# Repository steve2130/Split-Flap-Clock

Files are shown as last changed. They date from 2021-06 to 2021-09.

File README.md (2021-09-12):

# Split Flap Clock
I'm addicted to split flap display after accidently watching some Youtube videos. I want to make one for myself, however, choices in the market are either kinda crap or too expensive for a sucker like me.
So I try to make one.

So this flap clock is basically a clone of Solari Cifra 3 (the same company who made airports' flap boards). Instead of making a simple clock like Cifra 3, I decided to fuck myself up and make one that has different functions. Timer, Stopwatch, update time automatically with a NTP server, something like that. 

So basically you will see some fucked up CADs and some stupid code in the future. Hopefully I can actually make a workable clock. 
  
## Extra reading  
gregerw (https://github.com/gregerw/Split-flap-display)  
Tom Lynch (http://unknowndomain.co.uk/)  
JON-A-TRON (https://www.instructables.com/Split-Flap-Display/)  
Danica Evering (http://solaris.concordia.ca/)  
TheBeachLab (https://github.com/TheBeachLab/alphabets/tree/master/V1)  
Scott Bezek (https://github.com/scottbez1/splitflap)  
  
Some parents from the Vestaboard  
https://patents.google.com/patent/US10699605B1  
https://patents.google.com/patent/US20210005116A1

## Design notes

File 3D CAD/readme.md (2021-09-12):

You should see .stl and .f3z here.  
Use Fusion 360 to open .f3z  
.stl is only for viewing on GitHub.

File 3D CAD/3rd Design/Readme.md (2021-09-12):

f for the previous design. It's too big.  
This design is 120mm(L) 65mm(W) 85mm(H) big, so it should be ok now.  
  
No f3z because it is too big (>25MB)

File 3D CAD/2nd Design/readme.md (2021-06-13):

# 2nd Design
So this design is *way* better than the previous version.  
Shout out to gregerw (https://github.com/gregerw/Split-flap-display) for his brillant idea on the structure. ~~I copied it~~  
However, it is going to cost more than the previous design. All the structure of this design is going to be 3D printed.  
  
**This design might be too big tho**

## Component (Provisonal)  
Motor: 2x 28BYJ-48 (5V) *should be ok?*  
Hall effect sensor: 2x KY-003  
Controller: 1x Arduino Nano  
Power source: 2x 18650 in serial

Trying to control 2x 28BYJ-48 motor with 1x ULN2003. However, ULN2003 only have 7 pairs of in and out pins and I need 8. 74HC959 may be needed?  

## CAD source  
28BYJ-48 Motor model: https://grabcad.com/library/28byj-48-5

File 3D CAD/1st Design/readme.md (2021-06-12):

# First design

__This design is abandoned.__ 

This design uses 3mm MDF as the main structure for the hour and minute module.  
I was trying to design a structure so that it can be easily made with a laser cutter.   
However, the design I made was not strong enough for holding the entire structure together. It involved a LOT of friction mounts.  
As the center axis will going to be 3D printed anyway, this design is scrapped and I ~~shamelessly copied~~ made another design.

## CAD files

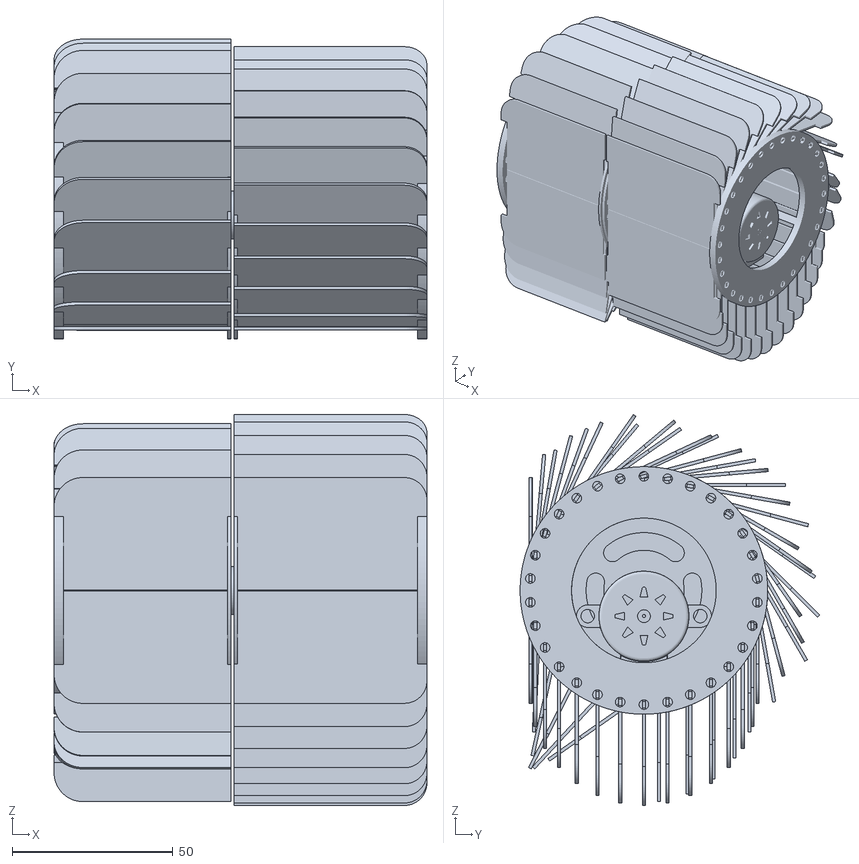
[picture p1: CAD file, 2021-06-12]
3D CAD/1st Design/Assembly.stl
116.0 x 93.2 x 121.6

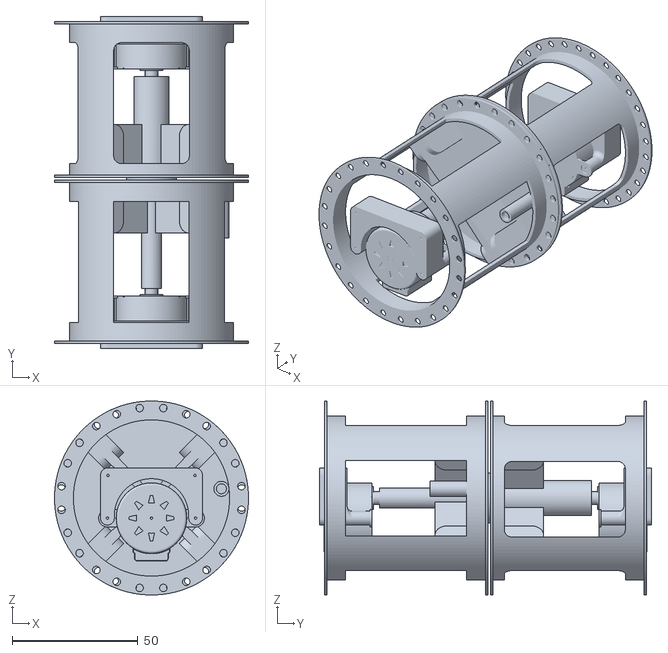
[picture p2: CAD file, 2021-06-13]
3D CAD/2nd Design/Ass-without-flaps.stl
77.0 x 131.8 x 77.0

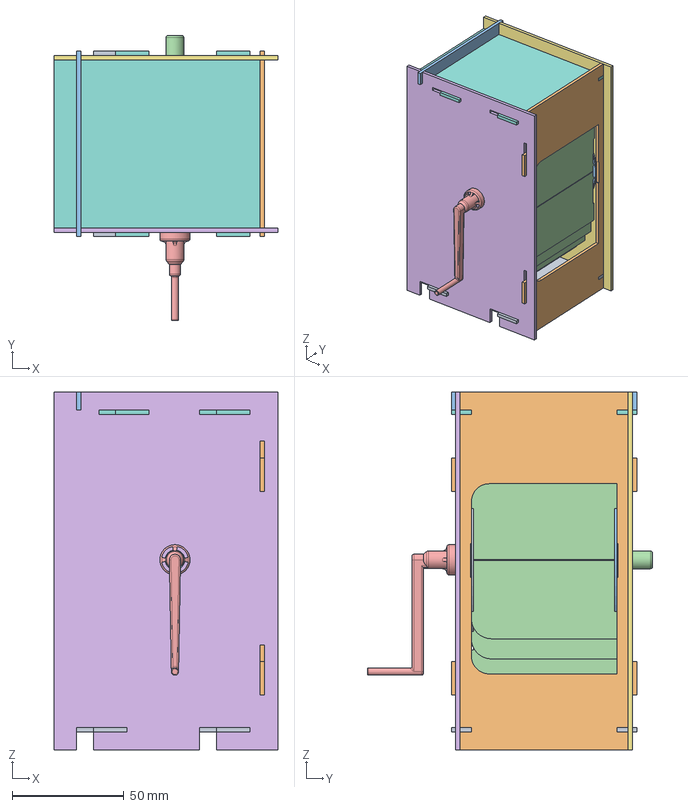
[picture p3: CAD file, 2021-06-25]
3D CAD/Test (Single Module)/Ass for testing v8.step
100.0 x 127.5 x 160.0 mm
Wheel
Axis
Wheel_1
Flap x 24
Turning Axis_1
Panel Left
Panel Right
Panel Top
Panel Bottom
Panel Front
Panel Back

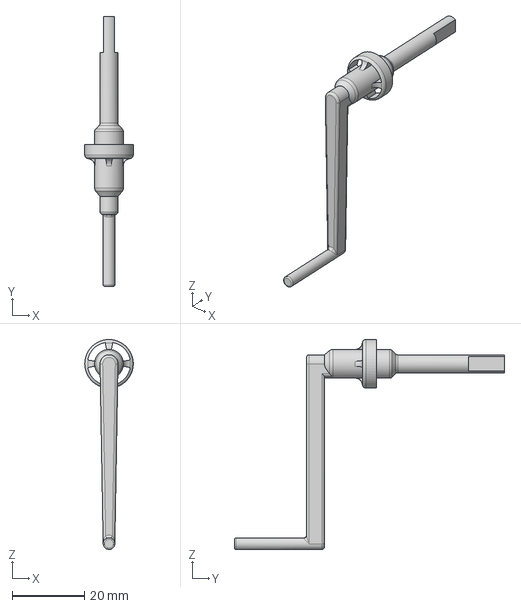
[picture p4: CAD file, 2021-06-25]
3D CAD/Test (Single Module)/Parts/Turning axis.step
13.5 x 75.0 x 58.3 mm

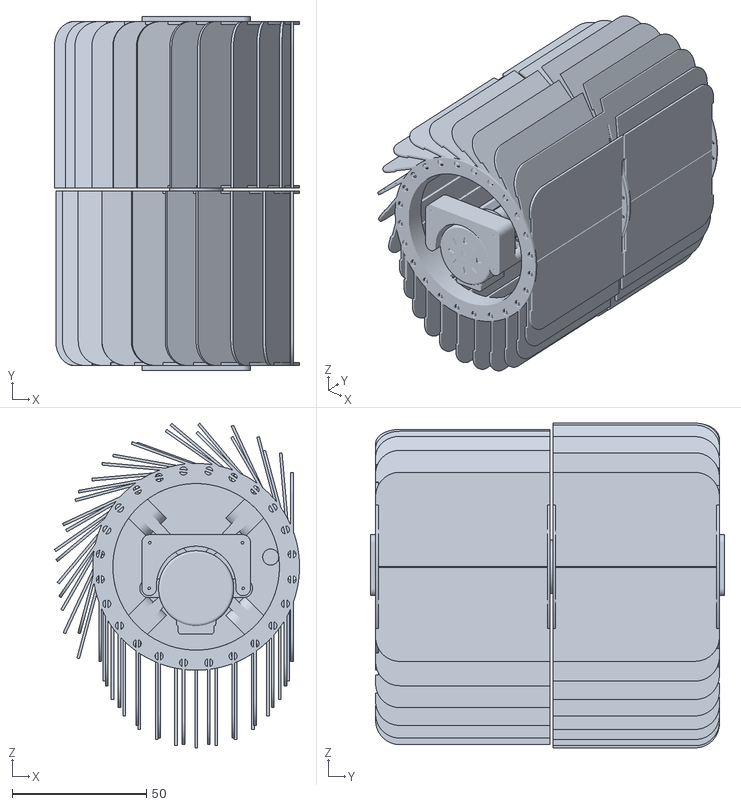
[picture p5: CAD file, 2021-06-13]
3D CAD/2nd Design/Ass-with-flaps.stl
91.3 x 131.8 x 120.9

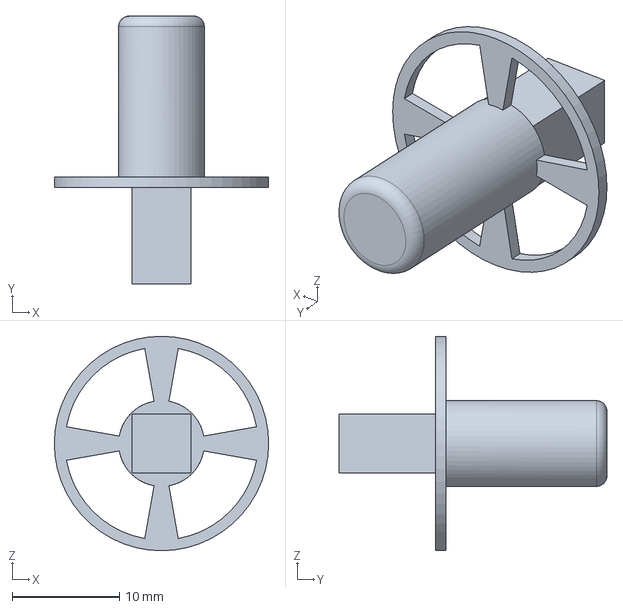
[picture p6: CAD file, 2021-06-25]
3D CAD/Test (Single Module)/Parts/Module Connector (For Test).step
20.0 x 25.0 x 20.0 mm

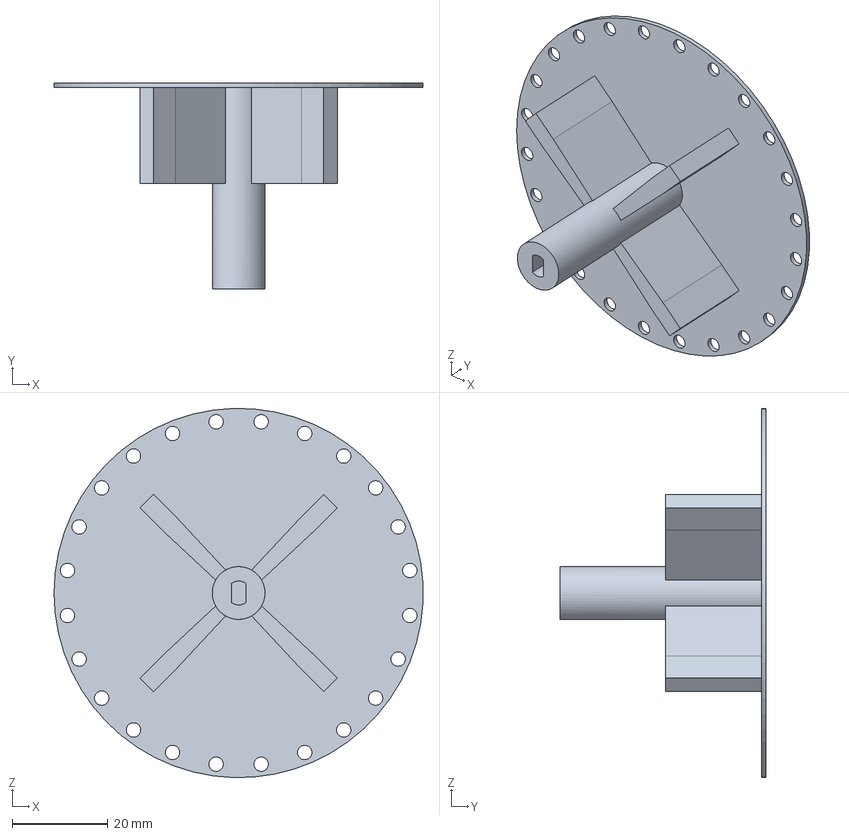
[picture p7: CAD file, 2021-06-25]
3D CAD/Test (Single Module)/Parts/Hour Wheel 2.step
76.9 x 43.0 x 77.0 mm

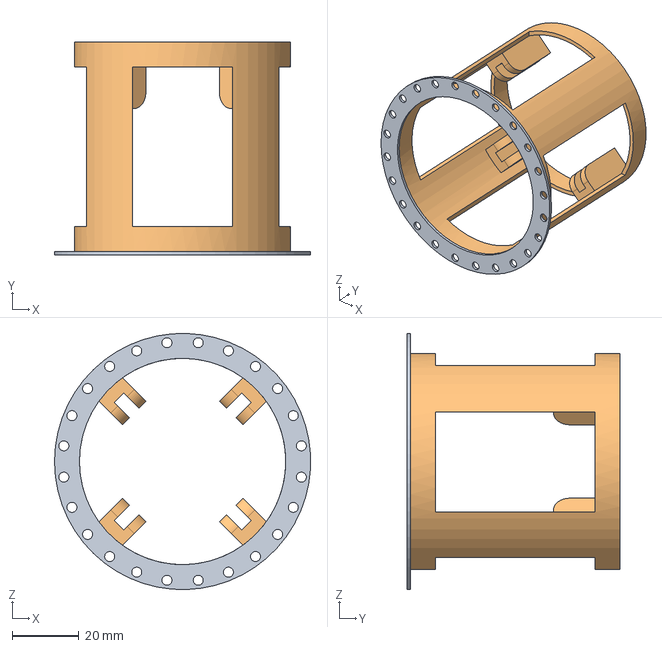
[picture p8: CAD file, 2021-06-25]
3D CAD/Test (Single Module)/Parts/Hour Wheel 1.step
76.9 x 64.0 x 77.0 mm
Wheel
Axis

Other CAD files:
2D Drawing/Flap_Demo-3.dwg
2D Drawing/Test (Single Module)/Hour Flaps Cut.dwg
2D Drawing/Flap_Demo.dwg
2D Drawing/Test (Single Module)/Test-parts-A3.dwg
3D CAD/1st Design/Assembly.f3z
3D CAD/2nd Design/Assembly .f3z
3D CAD/Test (Single Module)/Ass for testing v8.stl
3D CAD/Test (Single Module)/Ass for testing.f3z
3D CAD/Test (Single Module)/Parts/Hour Wheel 1.stl
3D CAD/Test (Single Module)/Parts/Hour Wheel 2.stl
3D CAD/Test (Single Module)/Parts/Module Connector (For Test).stl
3D CAD/Test (Single Module)/Parts/Turning axis.stl

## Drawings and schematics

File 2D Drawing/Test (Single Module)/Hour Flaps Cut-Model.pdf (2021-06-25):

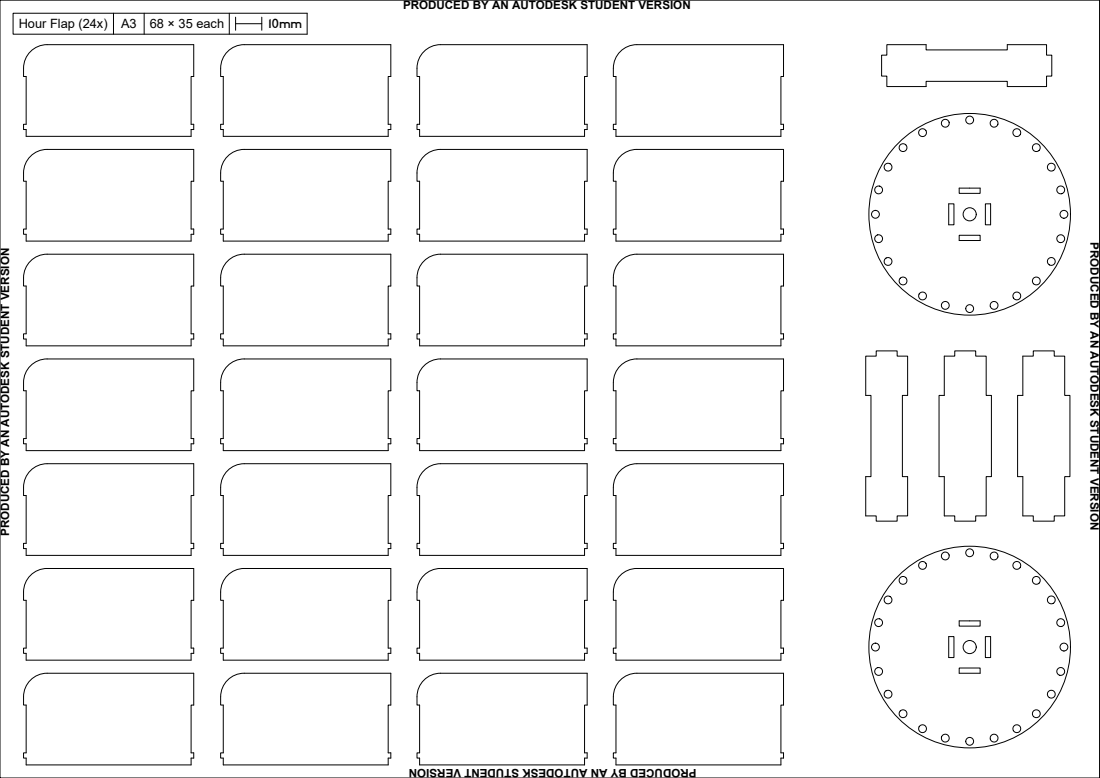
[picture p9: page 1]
Hour Flap (24x); 68 × 35 each

PRODUCED BY AN AUTODESK STUDENT VERSION

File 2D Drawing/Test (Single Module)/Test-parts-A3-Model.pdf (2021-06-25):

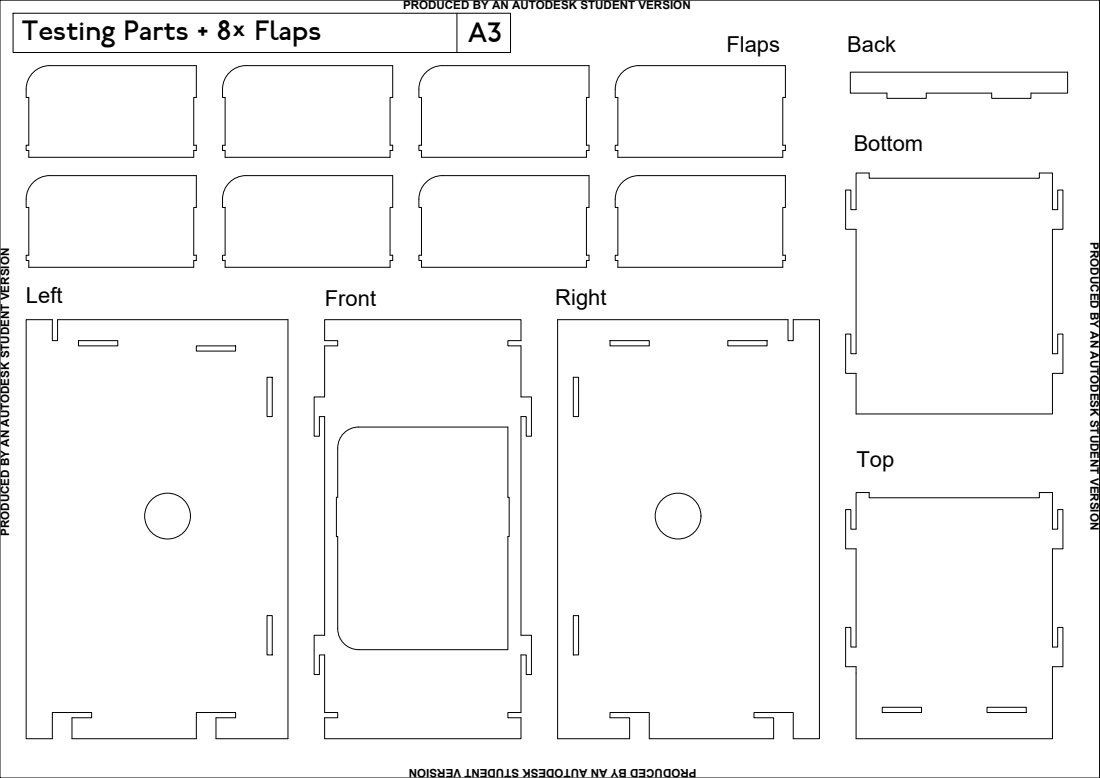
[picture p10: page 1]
Flaps; Back Testing Parts + 8× Flaps

PRODUCED BY AN AUTODESK STUDENT VERSION

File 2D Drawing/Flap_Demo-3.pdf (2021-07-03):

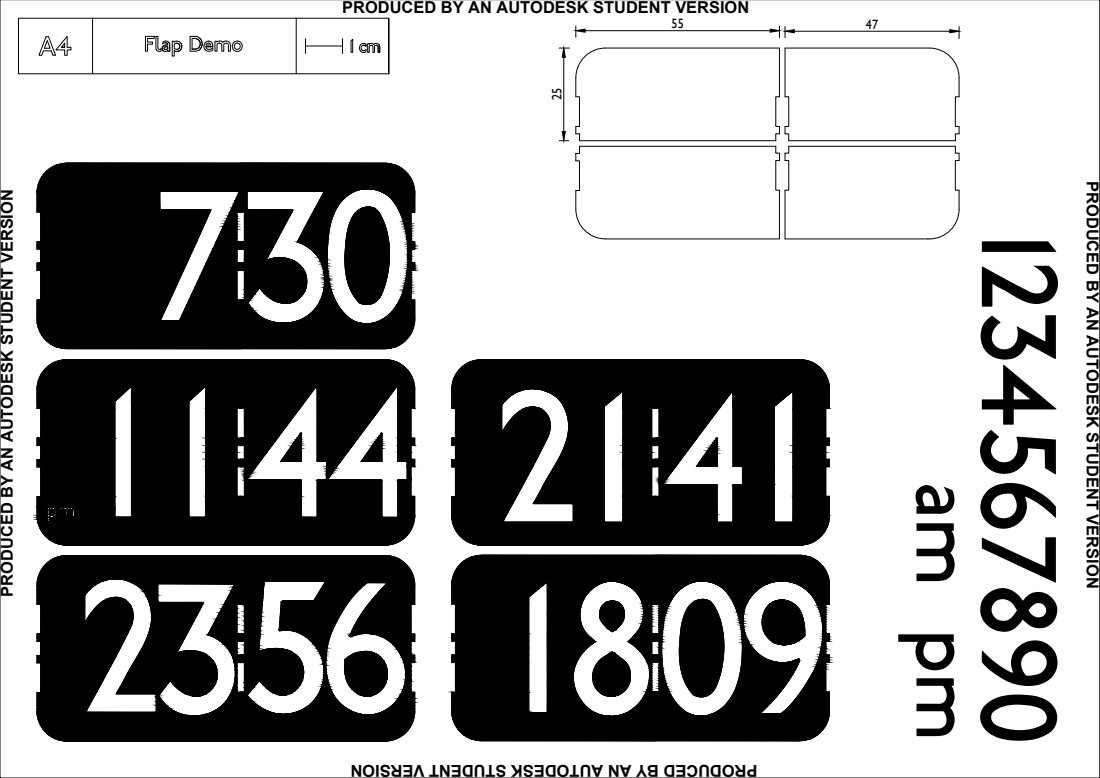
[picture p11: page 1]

PRODUCED BY AN AUTODESK STUDENT VERSION

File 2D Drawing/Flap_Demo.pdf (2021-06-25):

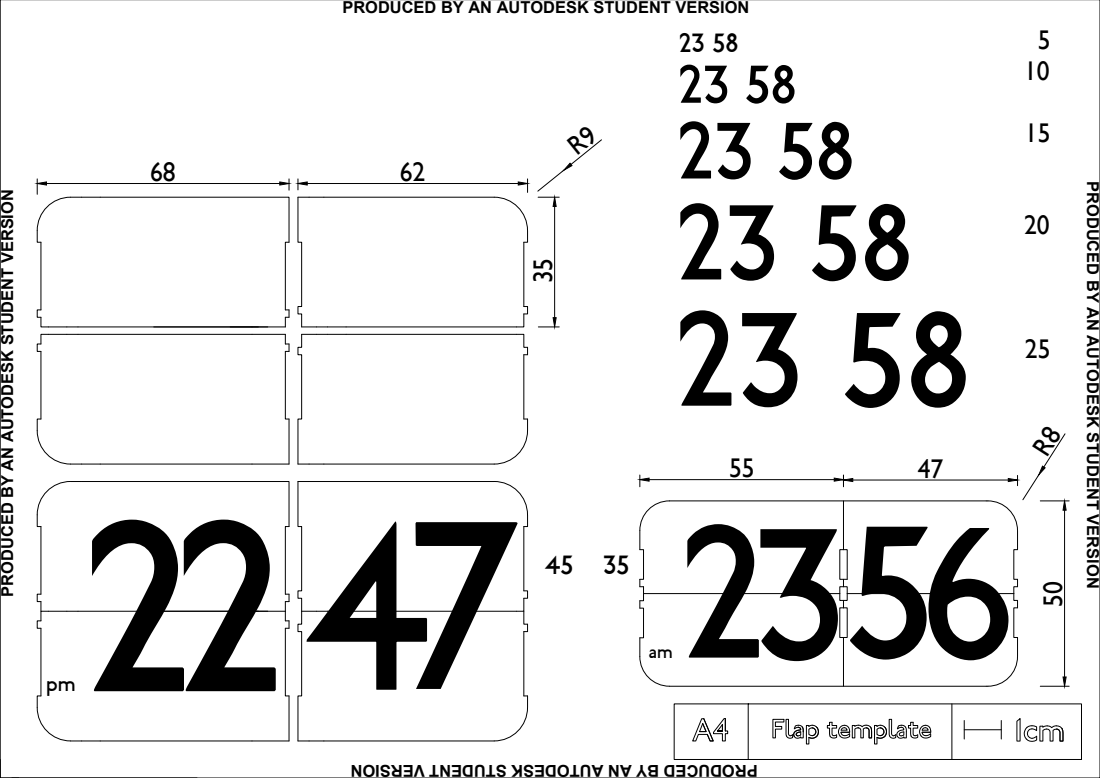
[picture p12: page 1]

PRODUCED BY AN AUTODESK STUDENT VERSION

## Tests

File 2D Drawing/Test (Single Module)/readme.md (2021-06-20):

# Test
Here you can find some 2D drawing.  

If you want to build this version as a prototype like me, remember that this design is designed to build with 2mm thick cardboard.  
Flaps and the shell/outer structure should be made with cardboard.  
Black cardboard looks way better than other colors imo.  

Remember that this design is only for test.  
Polypropylene is recommended for making flaps.   

Check the 3D model to know what's happening here.  
(https://github.com/steve2130/Split-Flap-Clock/tree/main/3D%20CAD/Test%20(Single%20Module))

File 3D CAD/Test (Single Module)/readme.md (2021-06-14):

# Test  
Use your hands instead of using motors.  
Motors are super overrated aren't they?  
  
Check the 3D model to understand what's happening.  
You can get the 2D drawings for the shell and flaps here  
(https://github.com/steve2130/Split-Flap-Clock/tree/main/2D%20Drawing/Test%20(Single%20Module))

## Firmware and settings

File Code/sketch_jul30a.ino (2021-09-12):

#include <Unistep2.h>

int sensor1 = 9;  //ky003
int sensor2 = 10;  //3144
int val1;
int val2;
long previousMillis = 0;
int StepperCountstep = 0;
Unistep2 stepperX(14, 12, 13, 15, 4096, 1000);
Unistep2 stepperY(5, 4, 0, 2, 4096, 1000);
int StepperStep = 137;
bool calibrating = false;

void setup()
{
  Serial.begin(115200);
  pinMode(sensor1, INPUT); //set sensor pin as input
  pinMode(sensor2, INPUT);
  pinMode(LED_BUILTIN, OUTPUT);
}

void loop() {
  digitalWrite(LED_BUILTIN, HIGH);
  
  val1 = digitalRead(sensor1);
  val2 = digitalRead(sensor2);
  if (val1 == LOW) {
    digitalWrite(LED_BUILTIN, LOW);  
    stepperX.run();
    stepperY.run();
    stepperX.moveTo(0);
    stepperY.moveTo(0);
  }

    if (val2 == LOW) {
    digitalWrite(LED_BUILTIN, HIGH);   
    long currentMillis = millis();
        if (currentMillis - previousMillis >= 2000) {
           previousMillis = currentMillis;
           stepperX.run();
           stepperX.move(-5000);
           Serial.print(val1);
           Serial.print(" ,  ");
           Serial.println(val2);
        }
  }

  else {
    digitalWrite(LED_BUILTIN, HIGH);
    long currentMillis = millis();
    stepperX.run();
    stepperY.run();
    if (currentMillis - previousMillis >= 1000) {
      previousMillis = currentMillis;
      StepperCountstep++;

      if (stepperY.stepsToGo() == 0 ){ 
        stepperY.move(StepperStep);
      }

      if (stepperX.stepsToGo() == 0 ){ 
        stepperX.move(StepperStep);
      }

      Serial.print(StepperStep);
      Serial.print(" ,  ");
      Serial.print(StepperCountstep);
      Serial.print(" ,  ");
      Serial.print(stepperX.currentPosition());
      Serial.print(" ,  ");
      Serial.println(stepperY.currentPosition());
      
      }
    }
  }

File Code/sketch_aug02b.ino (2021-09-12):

#include <Unistep2.h>
//Motor stops if hall effect sensor is activated


int sensor = 9;
int val;
long previousMillis = 0;
int StepperCountstep = 0;
Unistep2 stepperX(14, 12, 13, 15, 4096, 1000);// 
Unistep2 stepperY(5, 4, 0, 2, 4096, 1000);// 
int StepperStep = 137;
bool calibrating = false;

void setup()
{
  Serial.begin(115200);
  pinMode(sensor, INPUT); //set sensor pin as input
  pinMode(LED_BUILTIN, OUTPUT);
}

void loop() {
  digitalWrite(LED_BUILTIN, HIGH);
  
  val = digitalRead(sensor);
  if (val == LOW) {
    digitalWrite(LED_BUILTIN, LOW);   // turn the LED on (HIGH is the voltage level)
    stepperX.run();
    stepperY.run();
    stepperX.moveTo(0);
    stepperY.moveTo(0);
  }

  else {
    digitalWrite(LED_BUILTIN, HIGH);
    long currentMillis = millis();
    stepperX.run();
    stepperY.run();


      if (stepperX.stepsToGo() == 0 ){ 
        stepperX.move(StepperStep);
      }

      }
    }
  

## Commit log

2021-06-13 Add files via upload
    2021-06-13 [Provisional]
    [Ass-with-flaps.stl, Ass-without-flaps.stl, Assembly .f3z]
2021-07-03 Based on the smaller design showed on Demo 1
    [Flap_Demo-3.dwg]
2021-09-12 Testing motors and hall effect sensor
2021-09-12 Motor rotate and reporting its location
2021-09-12 Update and rename 3D CAD/3rd desgin/Readme.md to 3D CAD/3rd Design/Readme.md
